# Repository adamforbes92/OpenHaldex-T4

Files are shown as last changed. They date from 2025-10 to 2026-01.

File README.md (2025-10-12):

# OpenHaldex - Teensy 4.0

An open-source Generation 1, 2 & 4 Haldex Controller which originates/is a fork from ABangingDonk's 'OpenHaldex T4'.  It has been extended into Gen2 and Gen4 variants, with Gen3 and Gen5 currently unsupported.

### Concept
The basis of the module is to act as a middle man - read the incoming CAN frames destined for the OEM Haldex controller, and, if required, adjust these messages to 'trick' the Haldex into thinking more (or less) lock is required.  

### Teensy 4.0
The Teensy 4.0 microcontroller allows for two CAN streams with the use of the 'FlexCAN_T4' library.  Future boards are looking to move to ESP32 as this allows Apple support.

### The Modes
The controller allows for 4 main modes: Stock (act as OEM), FWD (zero lock), 7525 (some lock) and 5050 (100% lock) at the Haldex differential.  Generation 1, 2 and 4 have been tested on the bench to allow for a full understanding of what the stock CAN messages look like & therefore what messages need to be editted / created. 

The forked code has been tweaked to support the remote screen, standalone modes (so conversations/swaps into non-CANBUS) as well as Gen2 & Gen4 support.

### Uploading Code
For users wishing to customise or edit the code, it is released here for free use.  

For pre-compiled versions, navigate to the latest version and download the 'Teensy.exe' & your generation.  Connect the Haldex controller via. a data micro-USB cable (note some are ONLY power, so this needs to be checked).
Load the .hex file in Teensy.exe (File, Open) and press upload.  Some units may require the small internal white button to be pressed.

It is recommended to check back here regularly to find updates.

### The PCB & Enclosure
The Gerber files for the PCB, should anyone wish to build their own, is under the "PCB" folder.  This is the latest board.
Similarly, the enclosures are also here.
V2 enclosure continued to use the Deusche connector, which meant additional crimping & assembly.  
V3 enclosure moved to an onboard connector which results in a smaller footprint and less crimping.  

>Pinout & functionality remains the same for ALL generations of enclosure.

### Nice to Haves
The board supports broadcasting the Haldex output via. CAN - which allows pairing with the FIS controller to capture (and received) current and new modes.

Flashing LED if there is an issue with writing CAN messages.

Flashing LED to show installed Generation.

### Future / To Do
Incorporate 'live' switching of Generations.

## Disclaimer
It should be noted that this will modify Haldex operation and therefore can only be operated off-road and on a closed course.  

It should always be assumed that the unit may crash/hang or cause the Haldex to operate unprediably and caution should be exercised when in use.

Using this unit in any way will exert more strain on drivetrain components, and while the OEM safety features are still in place, it should be understood that having the Haldex unit locked up permanently may cause acceleated wear.

Forbes-Automotive takes no responsiblity for damages as a result of using this unit or code in any form.

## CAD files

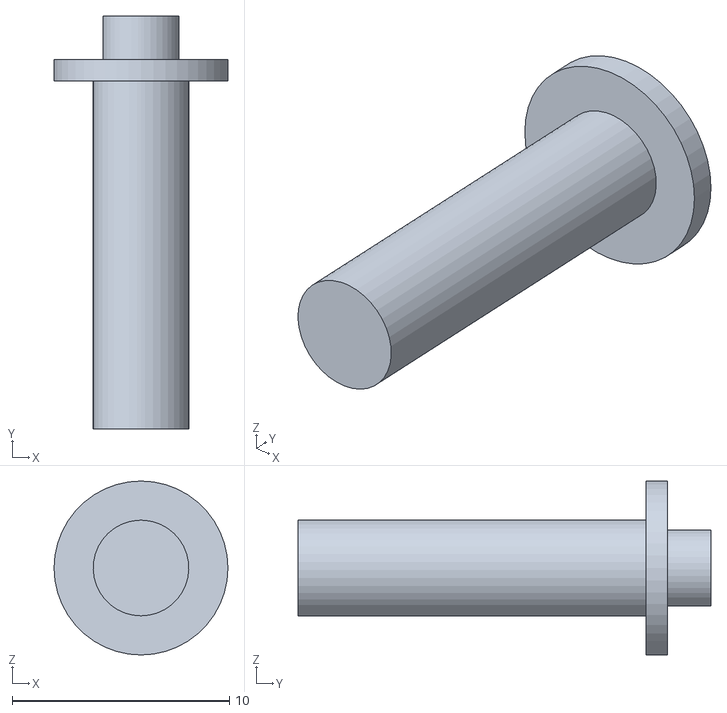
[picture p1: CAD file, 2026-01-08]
Enclosure/HaldexButtonV4.STL
8.00 x 19.0 x 8.00

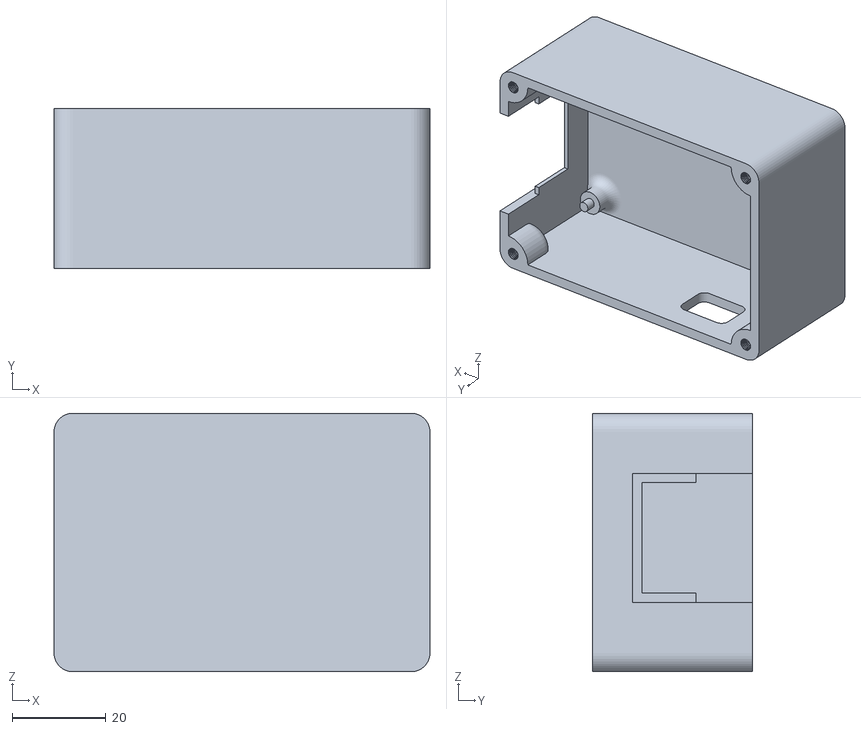
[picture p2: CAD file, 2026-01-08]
Enclosure/HaldexBoxV4.2.STL
80.0 x 34.0 x 55.0

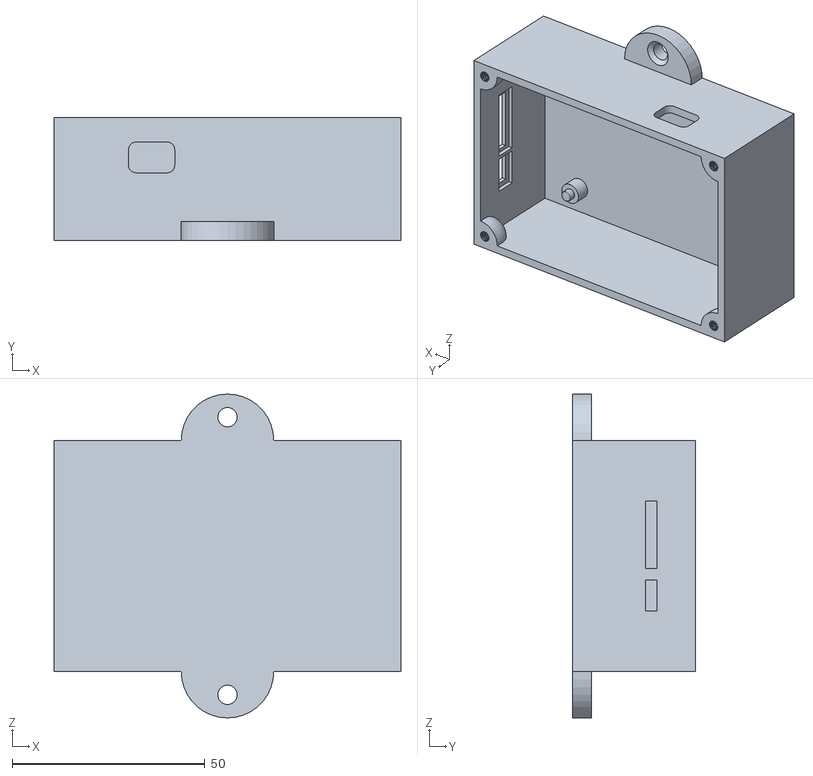
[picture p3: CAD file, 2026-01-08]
Enclosure/HaldexBox.STL
90.0 x 32.0 x 84.0

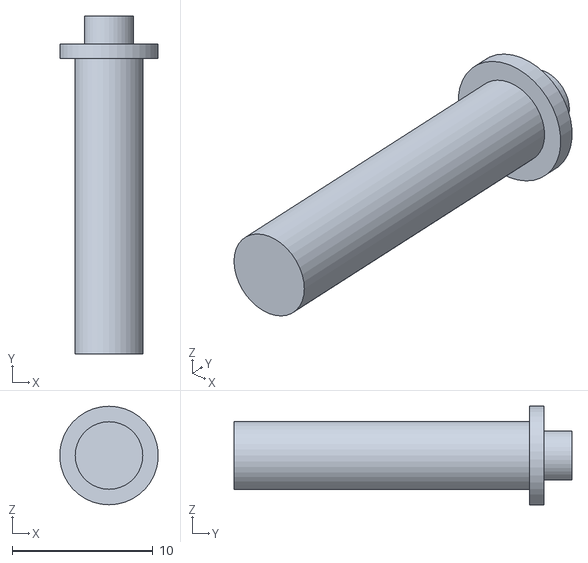
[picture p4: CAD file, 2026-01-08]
Enclosure/HaldexButton.STL
6.98 x 24.0 x 7.00

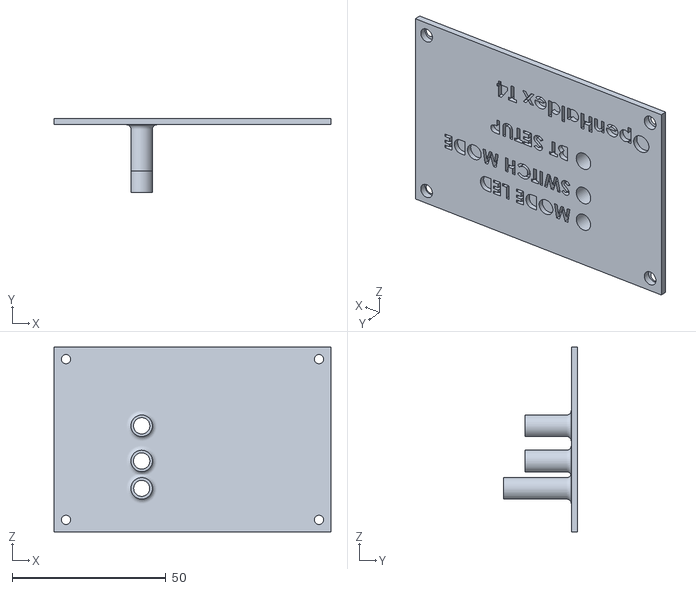
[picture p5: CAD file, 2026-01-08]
Enclosure/HaldexLid.STL
90.0 x 24.0 x 60.0

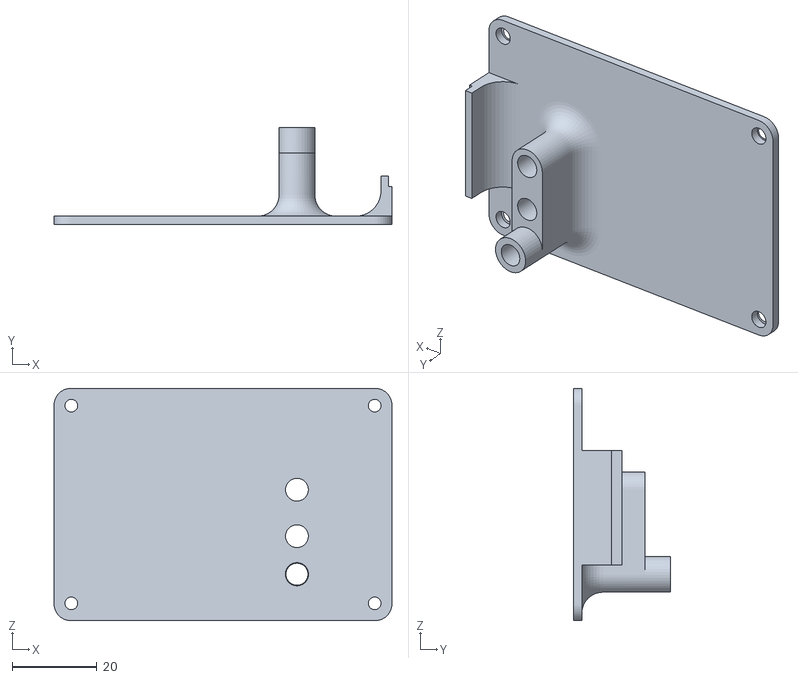
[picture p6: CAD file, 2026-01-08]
Enclosure/HaldexLidV4.STL
80.0 x 23.0 x 55.0

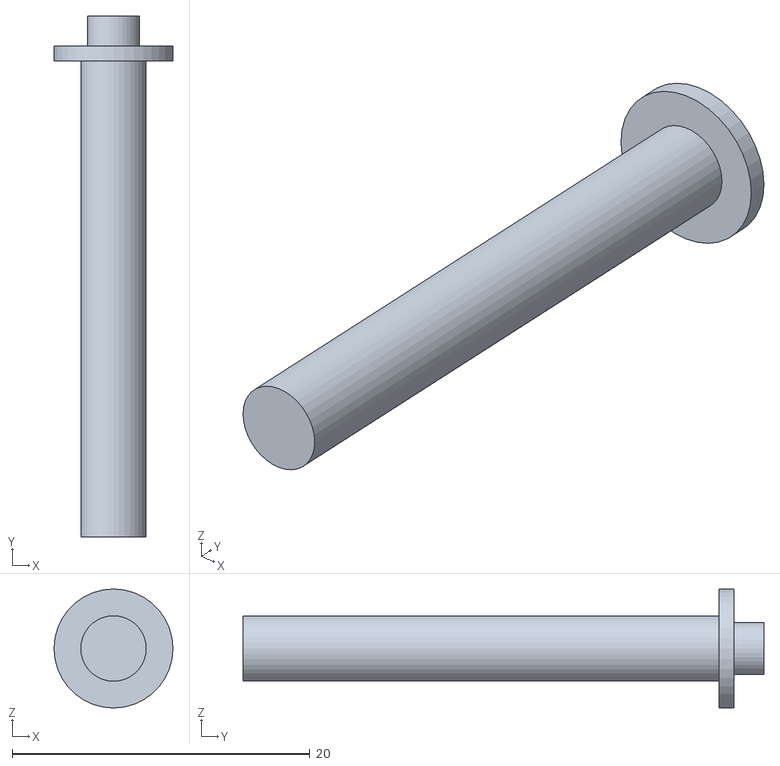
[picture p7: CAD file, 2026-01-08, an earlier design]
Enclosure/HaldexButtonV2.STL
8.00 x 35.0 x 8.00

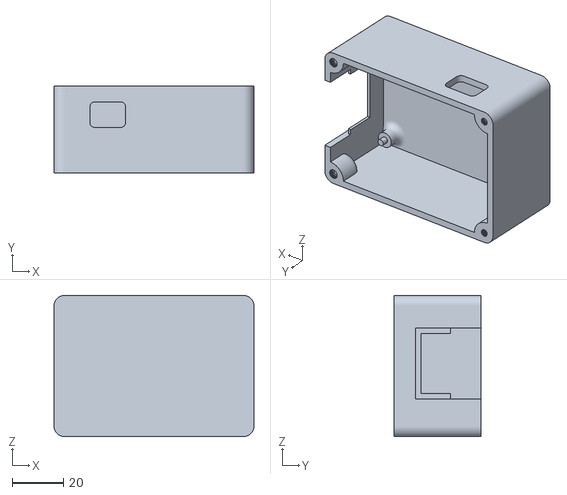
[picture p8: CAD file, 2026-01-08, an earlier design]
Enclosure/HaldexBoxV4.STL
78.0 x 34.0 x 55.0

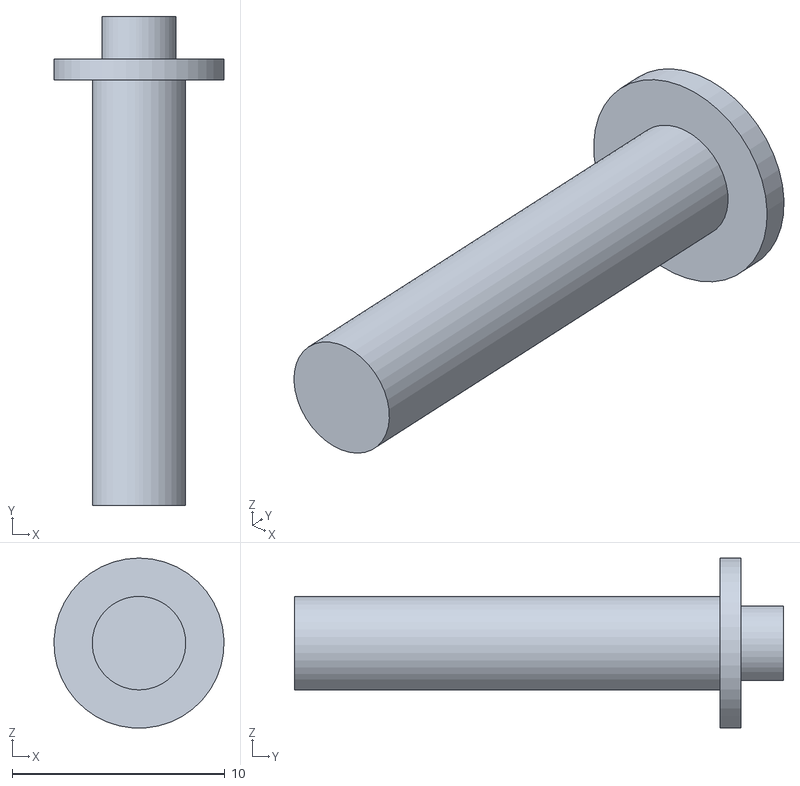
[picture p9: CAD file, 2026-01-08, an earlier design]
Enclosure/HaldexButtonV3.STL
7.99 x 23.0 x 7.99

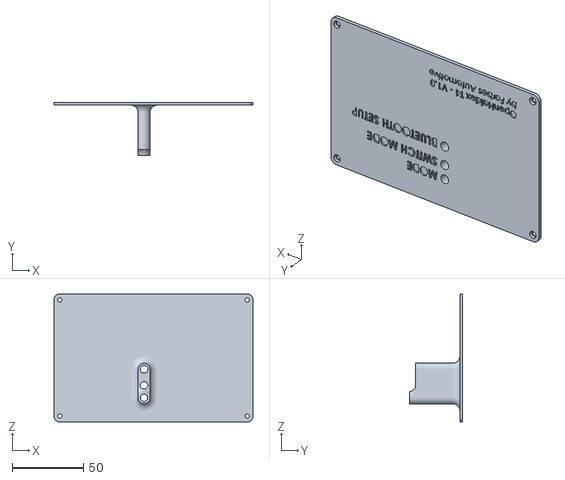
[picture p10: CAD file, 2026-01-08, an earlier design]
Enclosure/HaldexLidV2.STL
140.0 x 37.5 x 90.0

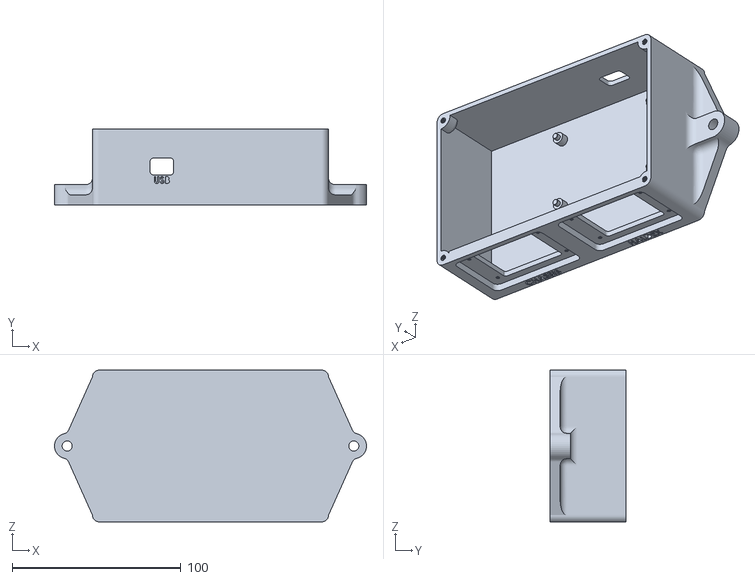
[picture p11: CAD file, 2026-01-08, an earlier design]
Enclosure/HaldexBoxV2.STL
185.0 x 45.0 x 90.0

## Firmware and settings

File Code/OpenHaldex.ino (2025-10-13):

/* OpenHaldex by Forbes-Automotive - re-documented/re-built by Vlad! 

Basic principles are to take the OEM CAN data from ECU (Motor)/ABS (Bremse)/Cluster (Kombi) etc and adjust before sending to the Haldex unit to force locking as requested.  
CAN Library for Teensy is interrupt driven so no work being done in the 'loop'.

Supports:
  Generation 1 as OEM & Standalone
  Generation 2 is OEM & Standalone
  Generation 4 as OEM & Standalone
  Generation 5 is currently unsupported(!)

Version History:
  Documented in '_vers.h'
*/

// Settings
#define HALDEX_GENERATION 4      // define number variable for generation.  Either 1, 2, 4.  3 (Volvo) and 5 (VW) unsupported AT THE MOMENT
#define SOFTWARE_VERSION 0x006C  // 0.108
#define BROADCAST_OPENHALDEX     // For FIS/aftermarket ECU/etc support.  Broadcasts OpenHaldex (& Haldex) data via. 0x6B0.  Comment out to disable - may conflict with other modules, confirm first(!)

// Debug (comment out to disable)
//#define ENABLE_DEBUG             // Enable Serial debug.  Comment out to disable
//#define DEBUG_HALDEXCAN_TRAFFIC  // Enable printing of Haldex CAN Traffic.  Comment out to disable
//#define DEBUG_CHASSISCAN_TRAFFIC  // Enable printing of Chassis CAN Traffic.  Comment out to disable

// Files
#include "openhaldex_definitions.h"
#include "openhaldex.h"
#include "openhaldex_gpio.h"
#include "openhaldex_bluetooth.h"
#include "openhaldex_can.h"
#include "openhaldex_calculations.h"
#include "openhaldex_eeprom.h"
#include "openhaldex_button.h"

// Timer used for repeating tasks
#include <arduino-timer.h>
auto timer = timer_create_default();

bool print_current_mode(void *params) {  // print the current mode & Haldex data in Serial
  DEBUG("Mode: %s", get_openhaldex_mode_string(state.mode));
  DEBUG("    Raw haldexEngagement: %d", received_haldex_state);

  // different Generations have different feedback.  Gen1 is JUST Byte 1, Gen2 is SUM of Byte 1 & Byte 4
  switch (HALDEX_GENERATION) {
    case 1:
      DEBUG("    Mapped haldexEngagement: %d", map(received_haldex_engagement, 128, 198, 0, 100));  // Byte 1, range is 128 to 198
      break;
    case 2:
      DEBUG("    Mapped haldexEngagement: %d", map(received_haldex_engagement, 128, 255, 0, 100));  // Byte 1 + Byte 4, range is 128 to 255
      break;
    case 4:
      DEBUG("    Mapped haldexEngagement: %d", map(received_haldex_engagement, 128, 255, 0, 100));
      break;
    default:
      DEBUG("    Mapped haldexEngagement: %d", map(received_haldex_engagement, 128, 198, 0, 100));
      break;
  }

  DEBUG("    reportClutch1: %d", received_report_clutch1);        // this means it has a clutch issue
  DEBUG("    haldexEngagement: %d", received_haldex_engagement);  // this is the lock %
  DEBUG("    reportClutch2: %d", received_report_clutch2);        // this means it also has a clutch issue
  DEBUG("    couplingOpen: %d", received_coupling_open);          // clutch fully disengaged
  DEBUG("    speedLimit: %d", received_speed_limit);              // hit a speed limit...
  DEBUG("    tempCounter2: %d", tempCounter2);                    // incrememting value for checking the response to vars...

  return true;
}

void setup() {
#ifdef ENABLE_DEBUG
  Serial.begin(115200);
  DEBUG("OpenHaldex - Teensy 4.0 @ %dMHz", F_CPU_ACTUAL / (1000 * 1000));
#endif

  DEBUG("Initialise CAN...");
  init_CAN();  // initialise CAN-BUS on Teensy

  DEBUG("Initialise EEPROM...");
  init_EEPROM();  // initialise EEPROM on Teensy (for reading last saved settings)

  timer.every(2500, bt_send_status);  // Update the Bluetooth connection every 2.5 seconds
  timer.every(2500, update_EEPROM);   // Update the values stored in EEPROM every 2.5 seconds

  timer.every(20, send_standalone_CAN);  // Emulate CAN frames for Standalone mode (if enabled).  May require multiple variants if Haldex expects frames in xx times(!)

#if (HALDEX_GENERATION == 4)
  if (in_standalone_mode) {
    timer.every(10, frames10);      // Emulate CAN frames for Standalone mode (if enabled)
    timer.every(20, frames20);      // Emulate CAN frames for Standalone mode (if enabled)
    timer.every(25, frames25);      // Emulate CAN frames for Standalone mode (if enabled)
    timer.every(100, frames100);    // Emulate CAN frames for Standalone mode (if enabled)
    timer.every(200, frames200);    // Emulate CAN frames for Standalone mode (if enabled)
    timer.every(1000, frames1000);  // Emulate CAN frames for Standalone mode (if enabled)
  }
#endif

  DEBUG("Initialise GPIO...");
  init_GPIO();  // initialise buttons, LED etc

  DEBUG("Initialise Bluetooth...");
  BT.begin(19200);  // speed to match LCD screen.  Phone app doesn't care.

#ifdef ENABLE_DEBUG
  timer.every(1000, print_current_mode);  // display the current mode every second.
#endif

#ifdef BROADCAST_OPENHALDEX
  timer.every(50, broadcast_openhaldex);  // broadcast OpenHaldex data every 50ms to CAN.
#endif
}

void loop() {
  timer.tick();  // update the timer

  // if too much time passed since the last Bluetooth message, a device is not connected
  if (millis() - last_bt_transmission_ms >= BT_TIMEOUT_MS) {
    bluetooth_connected = false;
  } else {  // a device is connected...
    bluetooth_connected = true;
  }

  // if there is Bluetooth data available, read and parse it
  if (BT.available()) {
    static bt_packet_t rx_packet;
    rx_packet.len = BT.readBytesUntil(BT_PACKET_END_BYTE, rx_packet.data, ARRAYSIZE(rx_packet.data));
    parse_bt_packet(rx_packet);
  }

  // if the Bluetooth Configuration button is pressed, start Bluetooth pairing
  if (digitalRead(GPIO_BT_CONF_BUTTON)) {
    DEBUG("BT button pressed in loop...");
    config_BT();
  }

  // light the LED according to the current mode
  show_current_mode_LED();
}

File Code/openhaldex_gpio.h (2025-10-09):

#ifndef OPENHALDEX_GPIO_H
#define OPENHALDEX_GPIO_H

// Pin assignments
#define GPIO_BT_CONF_BUTTON 4
#define GPIO_BT_RESET_SIGNAL 5
#define GPIO_MODE_BUTTON 17
#define GPIO_MODE_PCB 13
#define GPIO_LED_R 12
#define GPIO_LED_G 10
#define GPIO_LED_B 11

// Function prototype
void mode_button_ISR();

// Functions

void blinkLED(int duration, int flashes, uint8_t R, uint8_t G, uint8_t B) {
  for (int i = 0; i < flashes; i++) {
    analogWrite(GPIO_LED_R, R);
    analogWrite(GPIO_LED_G, G);
    analogWrite(GPIO_LED_B, B);
    delay(duration);
    analogWrite(GPIO_LED_R, 0);
    analogWrite(GPIO_LED_G, 0);
    analogWrite(GPIO_LED_B, 0);
    delay(duration);
  }
}

void init_GPIO() {
  // Disable unwanted Teensy optionals.
  CCM_ANALOG_PLL_AUDIO |= CCM_ANALOG_PLL_AUDIO_POWERDOWN;
  CCM_ANALOG_PLL_VIDEO |= CCM_ANALOG_PLL_VIDEO_POWERDOWN;
  CCM_ANALOG_PLL_ENET |= CCM_ANALOG_PLL_ENET_POWERDOWN;

  // Turn off the power LED.
  pinMode(LED_BUILTIN, OUTPUT);

  // Configure the RGB LED pins as outputs.
  pinMode(GPIO_LED_R, OUTPUT);
  pinMode(GPIO_LED_G, OUTPUT);
  pinMode(GPIO_LED_B, OUTPUT);

  pinMode(GPIO_BT_CONF_BUTTON, INPUT);
  pinMode(GPIO_MODE_PCB, INPUT);

  // If the Bluetooth Configuration button is held at startup, flash the Haldex Generation number.
  if (digitalRead(GPIO_BT_CONF_BUTTON)) {
    DEBUG("Show Haldex Ver.");
    blinkLED(2000, HALDEX_GENERATION, 255, 0, 0);

    // Holding the Bluetooth Configuration button causes the HC-05 to go into AT mode.
    // Reset the HC-05 to the normal mode.
    pinMode(GPIO_BT_CONF_BUTTON, OUTPUT);
    pinMode(GPIO_BT_RESET_SIGNAL, OUTPUT);
    digitalWrite(GPIO_BT_RESET_SIGNAL, LOW);
    digitalWrite(GPIO_BT_CONF_BUTTON, LOW);
    delay(2500);
    pinMode(GPIO_BT_RESET_SIGNAL, INPUT);
    pinMode(GPIO_BT_CONF_BUTTON, INPUT);
  }

  // Attach an interrupt to the Mode button.
  attachInterrupt(GPIO_MODE_BUTTON, mode_button_ISR, HIGH);
}

void show_current_mode_LED() {
  switch (state.mode) {
    case MODE_STOCK:
      analogWrite(GPIO_LED_R, 10);
      analogWrite(GPIO_LED_G, 0);
      analogWrite(GPIO_LED_B, 0);
      break;
    case MODE_FWD:
      analogWrite(GPIO_LED_R, 0);
      analogWrite(GPIO_LED_G, 10);
      analogWrite(GPIO_LED_B, 0);
      break;
    case MODE_5050:
      analogWrite(GPIO_LED_R, 0);
      analogWrite(GPIO_LED_G, 0);
      analogWrite(GPIO_LED_B, 10);
      break;
    case MODE_7525:
      analogWrite(GPIO_LED_R, 0);
      analogWrite(GPIO_LED_G, 5);
      analogWrite(GPIO_LED_B, 5);
      break;
    case MODE_CUSTOM:
      analogWrite(GPIO_LED_R, 5);
      analogWrite(GPIO_LED_G, 0);
      analogWrite(GPIO_LED_B, 5);
      break;
    default:
      break;
  }
}

#endif

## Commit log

2025-10-09 V1.12
    Gen1 updated - bug between OpenHaldex and FISCuntrol - CAN ID sharing issue. Moved ID and issue gone. Found locking issue in Motor1 - standalone reported 100% but OEM did not. Amended to make OEM work.
    [OpenHaldex.ino, openhaldex_can.h]
2025-10-11 V1.12
    Gen4 Standalone & OEM Merged. Added a full Gen4 Powertrain read (all modules).
    [gen4 boab read.xlsx]
2026-01-08 Enclosures
    Added
    [HaldexBox.STL, HaldexBoxV2.STL, HaldexBoxV4.2.STL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]
